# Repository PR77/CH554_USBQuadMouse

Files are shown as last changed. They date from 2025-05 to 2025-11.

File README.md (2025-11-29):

# CH554 USB MOUSE + KEYBOARD <-> AMIGA X-LATER
USB MOUSE + KEYBOARD <-> AMIGA X-LATER based on the WCH554 MCS51 based chip with USB Device + Host Interface. 

# Warning
This design has not been compliance tested and will not be. It may cause personal damage to you or others. I take no responsibility for this. I accept no responsibility for any damage to any equipment that results from the use of this design and its components. IT IS ENTIRELY AT YOUR OWN RISK!

# Overview
This project allows you to use a USB mouse or keyboard on an Amiga computer - of course only one-or-the-other is supported at any one time. It essentially converts a USB mouse to generate a quadrature signal stream, similarly it converts a USB keyboard keycodes (currently only DE is implemented) to work with an Amiga. There are many variants of such a project available, either using this micro controller or others, however I'm using this project as an opportunity to learn more about the WCH55x micro controller.

# Appearance Breadboard Version
I forgot to take a picture of the mess of wires breadboard version, so here is a picture on some perf-board instead. I'm using the USB B socket for debugging and the USB A socket is for the Mouse Connection. Of course only 1 device (either PC for debugging or Mouse for using) can be connected. I got the two USB sockets from an old printer board I found lying around the house.

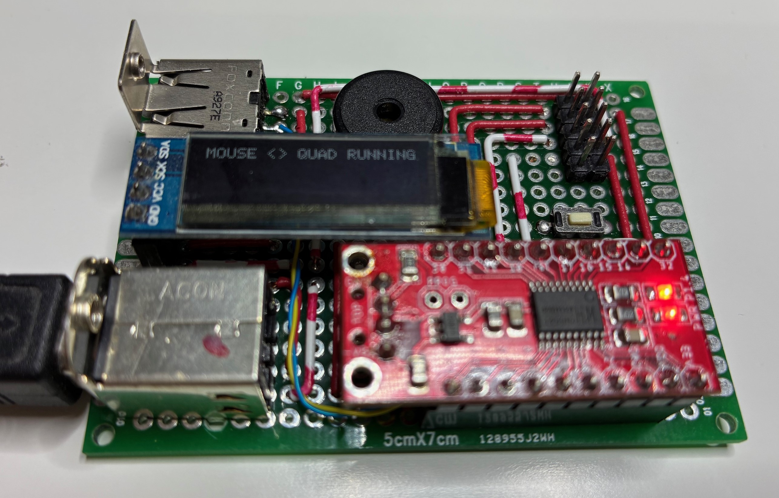
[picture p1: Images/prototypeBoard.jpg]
Perfboard


# Appearance Final PCB Version
PCB version has been routed and manufactured for supporting a mouse or keyboard. Here is the usual 3D artwork of the design.

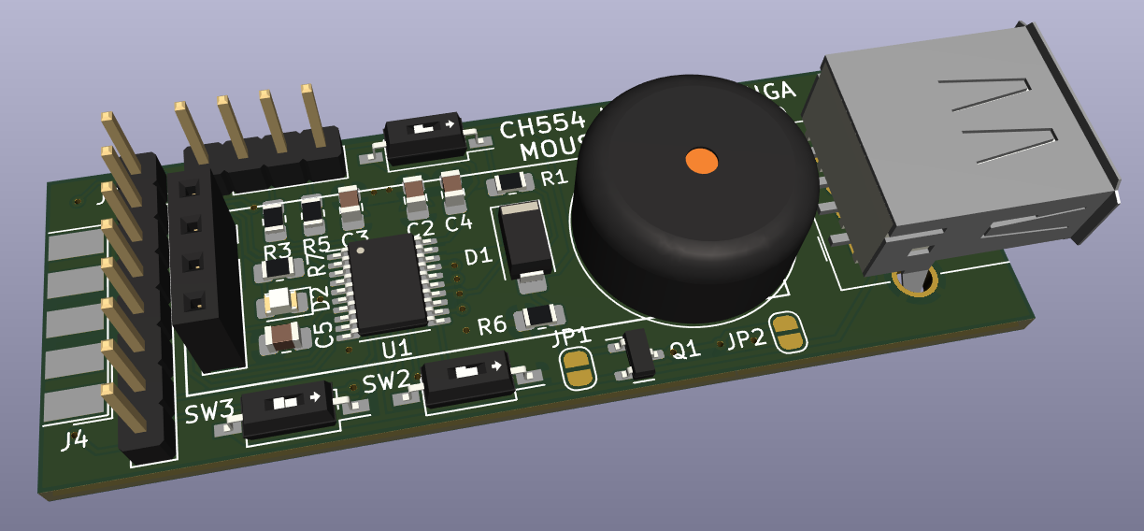
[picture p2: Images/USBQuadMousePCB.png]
PCB


OLED is also supported so you can see some information for example keyboard and mouse report data.

# Credits
I refacted a lot of the original libraries into various software components. However there were some repos which provided me with excellent information, tools and resources;
- https://github.com/wagiminator
- https://github.com/Blinkinlabs/ch554_sdcc
- https://github.com/HonghongLu/CH554

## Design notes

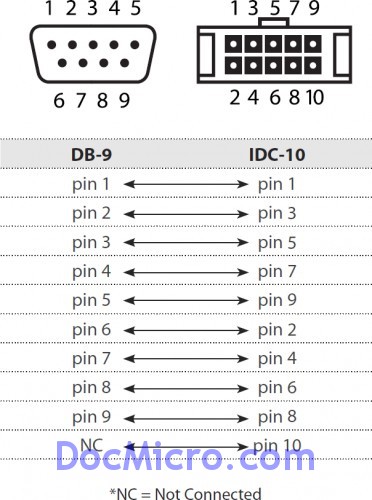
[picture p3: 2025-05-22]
Documents/DB_9 IDC_10.jpg

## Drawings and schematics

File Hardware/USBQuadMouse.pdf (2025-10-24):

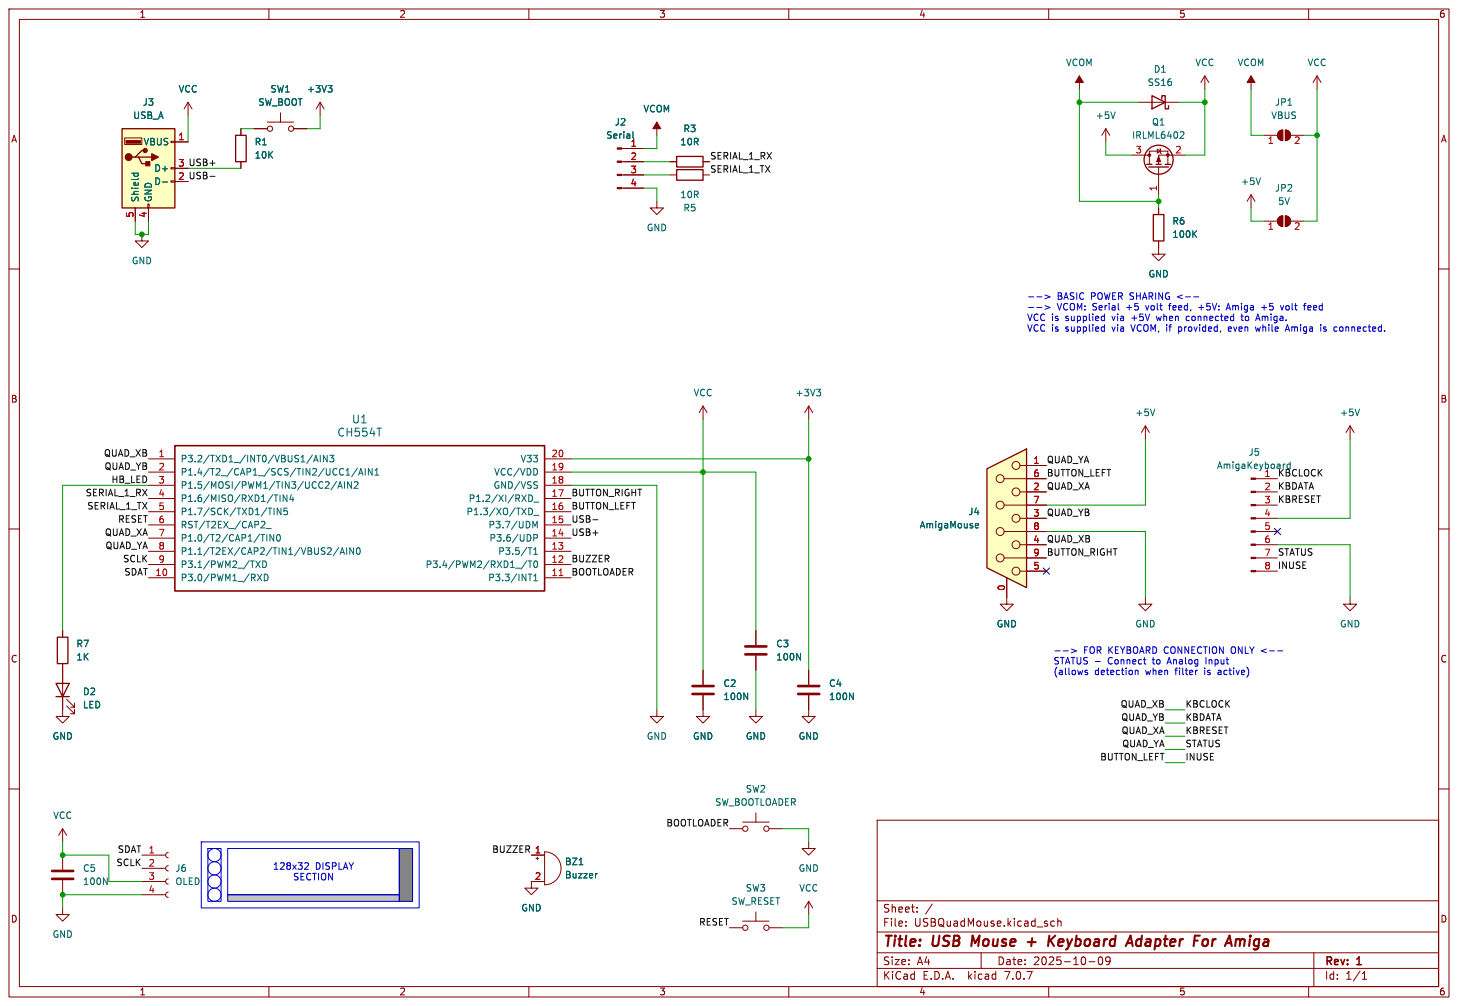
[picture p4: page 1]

File: USBQuadMouse.kicad_sch Sheet: /
Id: 1/1 Title: USB Mouse + Keyboard Adapter For Amiga

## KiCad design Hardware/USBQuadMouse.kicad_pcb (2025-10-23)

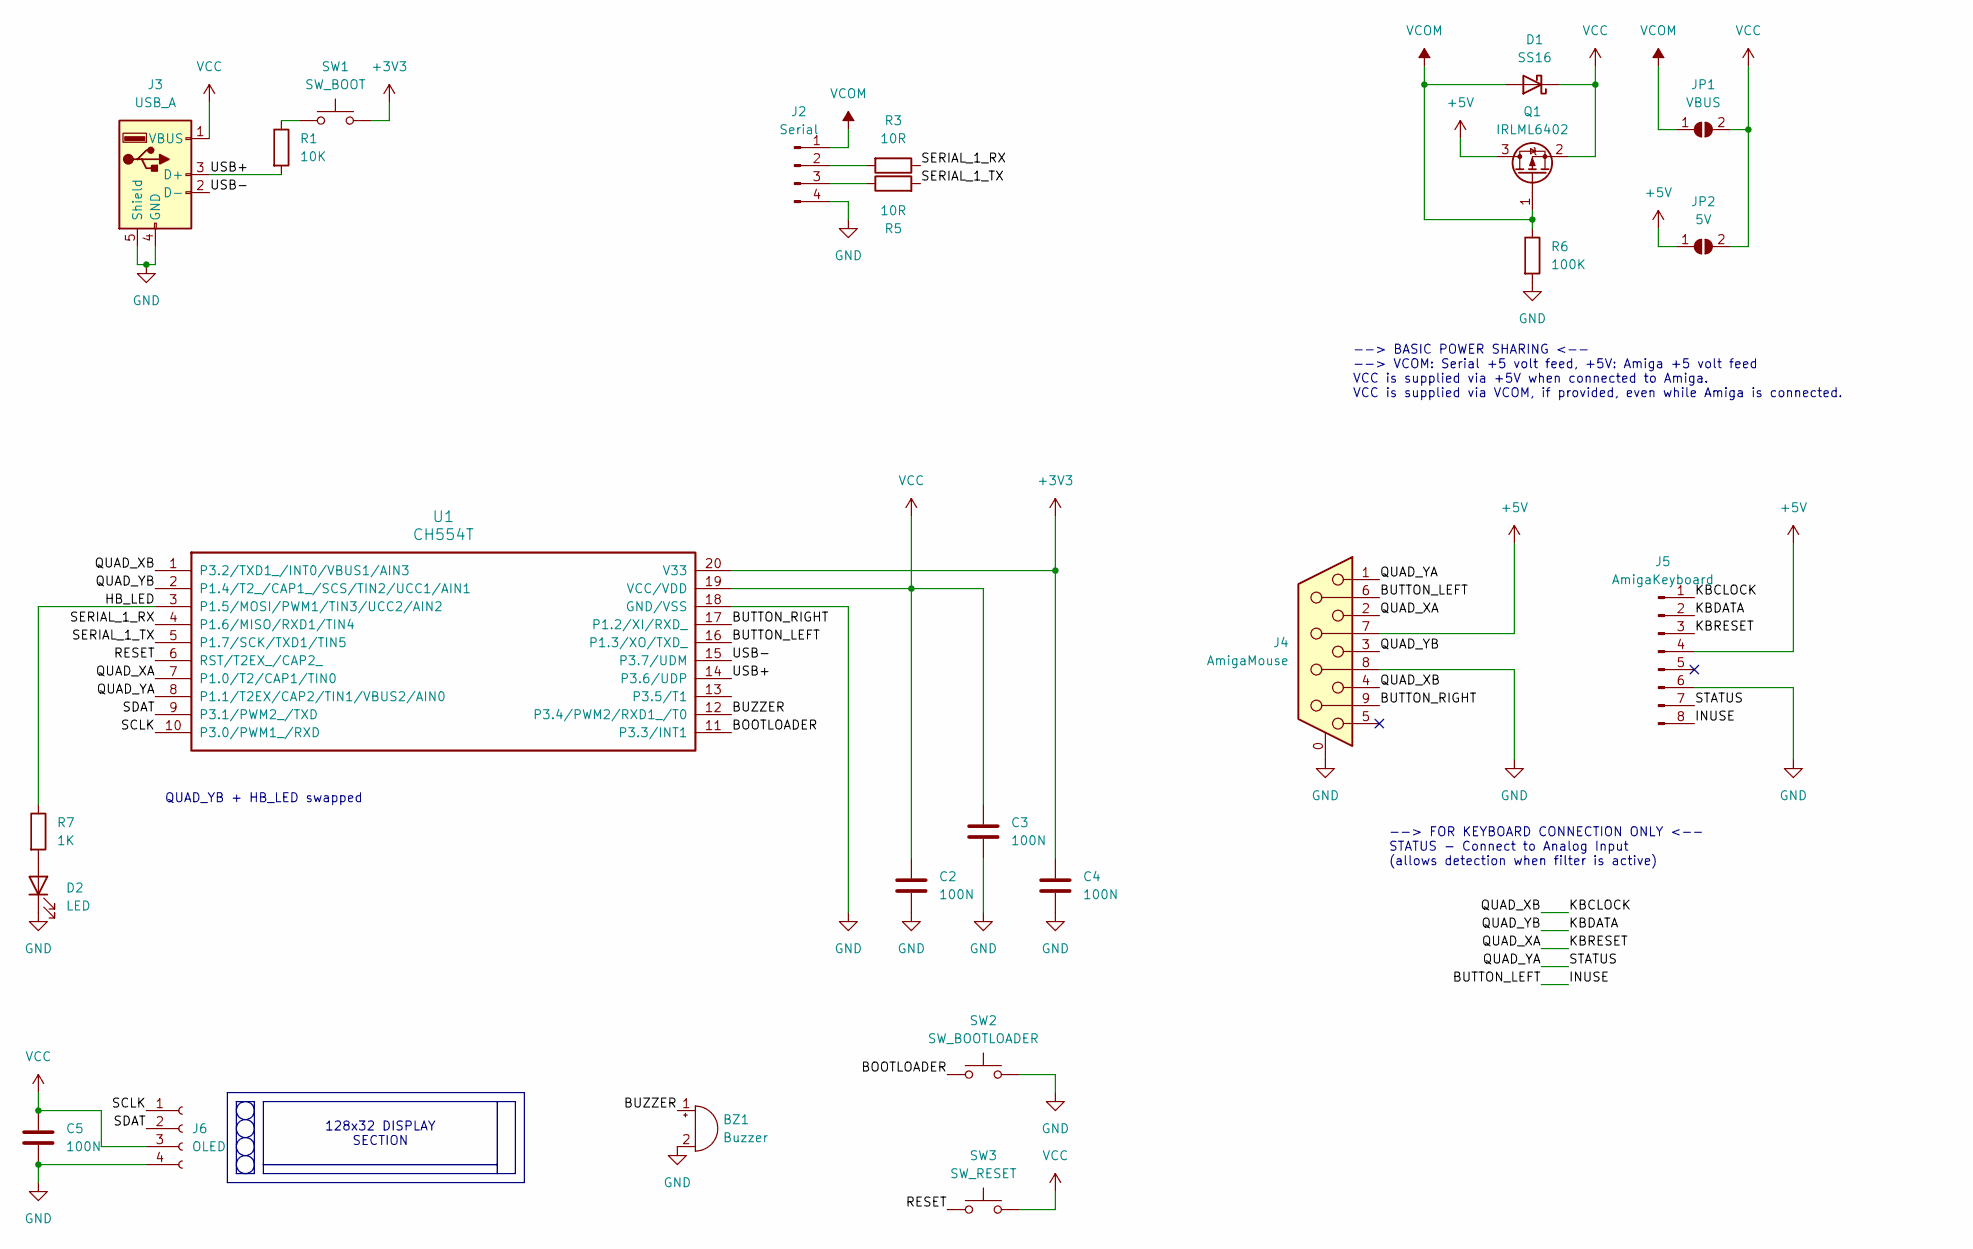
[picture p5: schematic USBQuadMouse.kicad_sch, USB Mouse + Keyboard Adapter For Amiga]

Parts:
BZ1: Buzzer; Buzzer_15x7.5RM7.6
C2, C3, C4, C5: 100N; C_0805_2012Metric_Pad1.18x1.45mm_HandSolder
D1: SS16; D_SMA
D2: LED; LED_0805_2012Metric_Pad1.15x1.40mm_HandSolder
J2: Serial; PinHeader_1x04_P2.54mm_Vertical
J3: USB_A; USB_A_Molex_67643_Horizontal
J4: AmigaMouse; DSUB-9_Female_EdgeMount_P2.77mm
J5: AmigaKeyboard; PinHeader_1x08_P2.54mm_Vertical
J6: OLED; PinSocket_1x04_P2.54mm_Vertical
JP1: VBUS; SolderJumper-2_P1.3mm_Open_RoundedPad1.0x1.5mm
JP2: 5V; SolderJumper-2_P1.3mm_Open_RoundedPad1.0x1.5mm
Q1: IRLML6402; SOT-23
R1: 10K; R_0805_2012Metric_Pad1.20x1.40mm_HandSolder
R3, R5: 10R; R_0805_2012Metric_Pad1.20x1.40mm_HandSolder
R6: 100K; R_0805_2012Metric_Pad1.20x1.40mm_HandSolder
R7: 1K; R_0805_2012Metric_Pad1.20x1.40mm_HandSolder
SW1: SW_BOOT; SW_DIP_SPSTx01_Slide_Copal_CHS-01B_W7.62mm_P1.27mm
SW2: SW_BOOTLOADER; SW_DIP_SPSTx01_Slide_Copal_CHS-01B_W7.62mm_P1.27mm
SW3: SW_RESET; SW_DIP_SPSTx01_Slide_Copal_CHS-01B_W7.62mm_P1.27mm
U1: CH554T; TSSOP-20_4.4x6.5mm_P0.65mm; LCSC C2928938

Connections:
+3V3: C4.1, SW1.2, U1.20 (V33)
+5V: J4.7, J5.4, JP2.1 (A), Q1.3 (D)
/BOOTLOADER: SW2.2, U1.11 (P3.3/INT1)
/BUTTON_LEFT: J4.6, J5.8, U1.16 (P1.3/XO/TXD_)
/BUTTON_RIGHT: J4.9, U1.17 (P1.2/XI/RXD_)
/BUZZER: BZ1.1 (-), U1.12 (P3.4/PWM2/RXD1_/T0)
/HB_LED: R7.1, U1.3 (P1.5/MOSI/PWM1/TIN3/UCC2/AIN2)
/KBCLOCK: J4.4, J5.1, U1.1 (P3.2/TXD1_/INT0/VBUS1/AIN3)
/KBDATA: J4.3, J5.2, U1.2 (P1.4/T2_/CAP1_/SCS/TIN2/UCC1/AIN1)
/KBRESET: J4.2, J5.3, U1.7 (P1.0/T2/CAP1/TIN0)
/QUAD_YA: J4.1, J5.7, U1.8 (P1.1/T2EX/CAP2/TIN1/VBUS2/AIN0)
/RESET: SW3.1, U1.6 (RST/T2EX_/CAP2_)
/SCLK: J6.1, U1.10 (P3.0/PWM1_/RXD)
/SDAT: J6.2, U1.9 (P3.1/PWM2_/TXD)
/SERIAL_1_RX: R3.1, U1.4 (P1.6/MISO/RXD1/TIN4)
/SERIAL_1_TX: R5.2, U1.5 (P1.7/SCK/TXD1/TIN5)
/USB+: J3.3 (D+), R1.2, U1.14 (P3.6/UDP)
/USB-: J3.2 (D-), U1.15 (P3.7/UDM)
GND: BZ1.2 (+), C2.2, C3.2, C4.2, C5.2, D2.1 (K), J2.4, J3.4 (GND), J3.5 (Shield), J4.0 (PAD), J4.8, J5.6, J6.4, R6.2, SW2.1, U1.18 (GND/VSS)
unnamed: D2.2 (A), R7.2
unnamed: J2.2, R3.2
unnamed: J2.3, R5.1
unnamed: R1.1, SW1.1
VCC: C2.1, C3.1, C5.1, D1.1 (K), J3.1 (VBUS), J6.3, JP1.2 (B), JP2.2 (B), Q1.2 (S), SW3.2, U1.19 (VCC/VDD)
VCOM: D1.2 (A), J2.1, JP1.1 (A), Q1.1 (G), R6.1

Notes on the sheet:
128x32 DISPLAY SECTION
--> BASIC POWER SHARING <-- --> VCOM: Serial +5 volt feed, +5V: Amiga +5 volt feed VCC is supplied via +5V when connected to Amiga. VCC is supplied via VCOM, if provided, even while Amiga is connected.
QUAD_YB + HB_LED swapped
--> FOR KEYBOARD CONNECTION ONLY <-- STATUS - Connect to Analog Input (allows detection when filter is active)

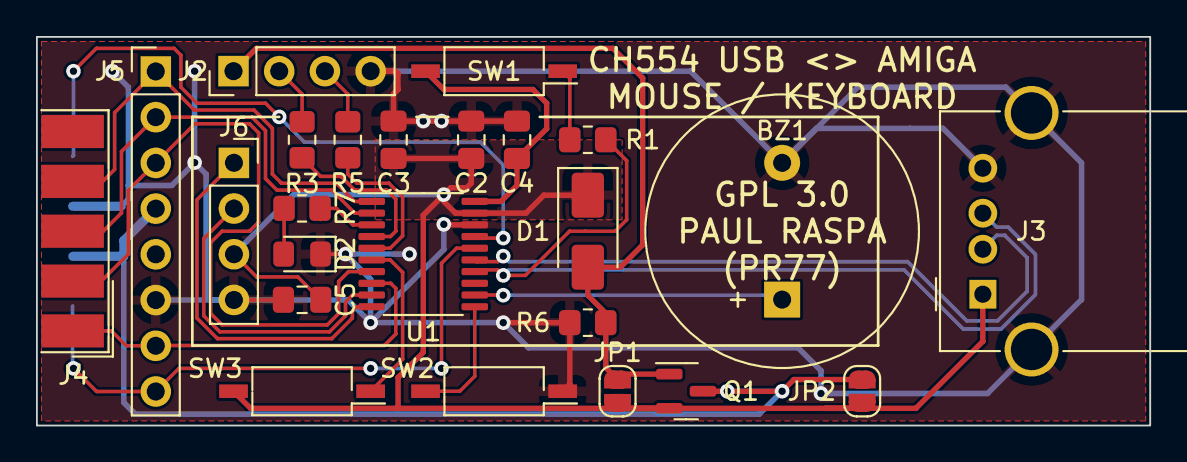
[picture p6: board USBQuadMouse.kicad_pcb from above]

Board: 2 copper layers, 61.8 x 21.6 mm, 24 parts (0 on the bottom side), 25 nets.

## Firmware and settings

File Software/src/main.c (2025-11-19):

/********************************** (C) COPYRIGHT *******************************
* File Name     : MAIN.c
* Author        : Paul Raspa (PR77)
* License       : MIT
* Version       : V1.0
* Date          : 2024/12/17
* Description   : CH554 USB MOUSE + KEYBOARD <-> AMIGA X-LATER
*******************************************************************************/

#include <stdint.h>
#include <compiler.h>
#include "ch554.h"
#include "heartbeat.h"
#include "system.h"
#include "tick.h"
#include "quadrature.h"
#include "keyboard.h"
#include "mouse.h"
#include "buttons.h"
#include "buzzer.h"
#include "i2c.h"
#include "ssd1306.h"
#include "usbhost.h"
#include "serial.h"
#include "bootloader.h"

#define CONSOLE_DEBUG_ENABLED

#define LED_FLASH_RATE_MS           300
#define USB_TRANSFER_RATE_MS        2
#define BUZZER_ACTIVE_DURATION_MS   2

__code uint8_t SetupGetDevDescr[] = { USB_REQ_TYP_IN, USB_GET_DESCRIPTOR, 0x00, USB_DESCR_TYP_DEVICE, 0x00, 0x00, sizeof(USB_DEV_DESCR), 0x00 };
__code uint8_t SetupGetCfgDescr[] = { USB_REQ_TYP_IN, USB_GET_DESCRIPTOR, 0x00, USB_DESCR_TYP_CONFIG, 0x00, 0x00, 0x04, 0x00 };
__code uint8_t SetupSetUsbAddr[] = { USB_REQ_TYP_OUT, USB_SET_ADDRESS, USB_DEVICE_ADDR, 0x00, 0x00, 0x00, 0x00, 0x00 };
__code uint8_t SetupSetUsbConfig[] = { USB_REQ_TYP_OUT, USB_SET_CONFIGURATION, 0x00, 0x00, 0x00, 0x00, 0x00, 0x00 };
__code uint8_t SetupSetUsbInterface[] = { USB_REQ_RECIP_INTERF, USB_SET_INTERFACE, 0x00, 0x00, 0x00, 0x00, 0x00, 0x00 };
__code uint8_t SetupClrEndpStall[] = { USB_REQ_TYP_OUT | USB_REQ_RECIP_ENDP, USB_CLEAR_FEATURE, 0x00, 0x00, 0x00, 0x00, 0x00, 0x00 };
__code uint8_t SetupSetHIDIdle[]= { 0x21, HID_SET_IDLE, 0x00, 0x00, 0x00, 0x00, 0x00, 0x00 };
__code uint8_t SetupGetHIDDevReport[] = { 0x81, USB_GET_DESCRIPTOR, 0x00, USB_DESCR_TYP_REPORT, 0x00, 0x00, 0xFF, 0x00 };
__code uint8_t SetupGetHubDescr[] = { HUB_GET_HUB_DESCRIPTOR, HUB_GET_DESCRIPTOR, 0x00, USB_DESCR_TYP_HUB, 0x00, 0x00, sizeof(USB_HUB_DESCR), 0x00 };

__xdata uint8_t UsbDevEndp0Size;
__xdata __at (0x0000) uint8_t TxBuffer[MAX_PACKET_SIZE];  // OUT, must even address
__xdata __at (0x0040) uint8_t RxBuffer[MAX_PACKET_SIZE];  // IN, must even address

uint8_t Set_Port = 0;
__xdata _RootHubDev ThisUsbDev;                             // ROOT
__xdata _DevOnHubPort DevOnHubPort[HUB_MAX_PORTS];          // Assumption: no more than 1 external HUB, each external HUB does not exceed HUB_MAX_PORTS ports (don’t care if there are more)
__bit FoundNewDev;

#define LOG(msg)   {serial_printString(__FILE__); serial_printCharacter(' '); serial_printHexWord(__LINE__); serial_printCharacter(' '); serial_printString(msg); serial_printString("\n\r");}

void main(void) {
    static __xdata uint32_t previousCountLEDFlash = 0, previousCountUSBTransfer = 0;
    static __xdata uint8_t mouseInitialised = 0, keyboardInitialised = 0;
    uint8_t usbStatus = (uint8_t)ERR_USB_UNKNOWN, len = 0, endp = 0;
    uint16_t usbLocation = 0;

    // Setup low level system and bootloader
    system_disableGlobalInterupts();
    system_CfgFsys();
    bootloader_initialise();

    // Setup timer ticks
    tick_initialiseTimer0();
    tick_enableTimer0Interrupt();

    // Setup heartbeat LED
    heartbeat_initialise();

#if defined(CONSOLE_DEBUG_ENABLED)
    // Setup serial port (debug)
    serial_initialiseSerial1(SERIAL_BAUD_RATE, 0);
#endif // CONSOLE_DEBUG_ENABLED

    // Setup i2c and SSD1306 OLED
    i2c_initialise();
    ssd1306_initialise();
    ssd1306_clearScreen();

    // Setup and initialise USB host
    InitUSB_Host();

    // Setup buzzer with default frequency
    buzzer_initialise(0);

    // Start timer tick and enable global interrupts
    tick_startTimer0();
    system_enableGlobalInterupts();

    // Application code starts here ...
    ssd1306_setCursor(0, 0);
    ssd1306_printString("USB <-> AMIGA X-LATER");
#if defined(CONSOLE_DEBUG_ENABLED)
    serial_printString("\x1b[2J\x1b[HUSB MOUSE + KEYBOARD <-> AMIGA X-LATER RUNNING...\n\r");
#endif // CONSOLE_DEBUG_ENABLED

    while (1) {

#if defined(CONSOLE_DEBUG_ENABLED)
        uint16_t characterToEcho = serial_getCharacter(0);

        if ((characterToEcho != RECEIVE_TIMEOUT) && (characterToEcho != RECEIVE_NO_DATA_AVAIL)) {
            serial_printCharacter((char)characterToEcho);    
        }
#endif // CONSOLE_DEBUG_ENABLED

        if (bootloader_checkBootloaderRequest()) {
            buzzer_stopBuzzer();
            ssd1306_clearScreen();
            ssd1306_setCursor(0, 0);
            ssd1306_printString("---- BOOT LOADER ----");
            bootloader_enter();
        }

        if ((tick_get1msTimerCount() - previousCountLEDFlash) > LED_FLASH_RATE_MS) {
            previousCountLEDFlash += LED_FLASH_RATE_MS;

            heartbeat_toggleState();
        }

        if (UIF_DETECT) {
            UIF_DETECT = 0;
            usbStatus = AnalyzeRootHub();
            if (ERR_USB_CONNECT == usbStatus) {
                FoundNewDev = 1;

                ssd1306_setCursor(0, 1);
                ssd1306_printString("CONNECTED USB DEVICE ");
                ssd1306_setCursor(0, 2);
                ssd1306_printString("                     ");
                ssd1306_setCursor(0, 3);
                ssd1306_printString("                     ");
            }

            if (ERR_USB_DISCON == usbStatus) {
                FoundNewDev = 0;

                ssd1306_setCursor(0, 1);
                ssd1306_printString("REMOVED USB DEVICE   ");
                ssd1306_setCursor(0, 2);
                ssd1306_printString("                     ");
                ssd1306_setCursor(0, 3);
                ssd1306_printString("                     ");
            }
        }

        if (FoundNewDev) {
            FoundNewDev = 0;

            usbStatus = EnumAllRootDevice();
            if (ERR_SUCCESS != usbStatus) {
                ssd1306_setCursor(0, 2);
                ssd1306_printString("ENUMERATION ERROR  ");
                ssd1306_printHexByte(usbStatus);
            } else {
                // Logic to initialise / deinitialise Mouse or Keyboard depending
                // on what device has been inserted or removed.

                if (SearchTypeDevice(DEV_TYPE_KEYBOARD) != 0xFFFF) {
                    // Keyboard found and enumerated.

                    if (mouseInitialised) {
                        mouse_deinitialise();
                        mouseInitialised = 0;
                    }

                    if (!keyboardInitialised) {
                        // Setup Amiga keyboard emulation
                        keyboard_initialise();
                        buzzer_pulseBuzzer(BUZZER_ACTIVE_DURATION_MS);
                        keyboardInitialised = 1;
                    }
                }

                if (SearchTypeDevice(DEV_TYPE_MOUSE) != 0xFFFF) {
                    // Mouse found and enumerated.

                    if (keyboardInitialised) {
                        keyboard_deinitialise();
                        keyboardInitialised = 0;
                    }

                    if (!mouseInitialised) {
                        // Setup quadrature encoder and mouse button emulation
                        mouse_initialise();
                        buzzer_pulseBuzzer(BUZZER_ACTIVE_DURATION_MS);
                        mouseInitialised = 1;
                    }
                }  
            }
        }

        if (keyboardInitialised) {
            keyboard_cyclicHanlder();
        }

        if ((tick_get1msTimerCount() - previousCountUSBTransfer) > USB_TRANSFER_RATE_MS) {
            previousCountUSBTransfer += USB_TRANSFER_RATE_MS;

            // Keyboard emulation --->

            usbLocation = SearchTypeDevice(DEV_TYPE_KEYBOARD);
            if (usbLocation != 0xFFFF) {                                     // found a keyboard
                ssd1306_setCursor(0, 2);
                ssd1306_printString("KEYBOARD @ LOC ");
                ssd1306_printHexWord(usbLocation);
            
                ssd1306_setCursor(0, 3);
                SelectHubPort(usbLocation);                                 // select to operate designated ROOT-HUB port, set current USB speed and USB address of operated device
                usbLocation = usbLocation >> 8;                             // CH554 has only one USB, only the lower eight bits are required

                if (usbLocation) {
                    endp = DevOnHubPort[usbLocation-1].GpVar[0];            // address of interrupt endpoint, bit 7 is used for synchronization flag bit
                } else {
                    endp = ThisUsbDev.GpVar[0];
                }

                if (endp & USB_ENDP_ADDR_MASK) {                             // endpoint valid
                    // CH554 transmit transaction, get data, NAK does not retry
                    usbStatus = USBHostTransact(USB_PID_IN << 4 | endp & 0x7F, endp & 0x80 ? bUH_R_TOG | bUH_T_TOG : 0, 0);
                    if (usbStatus == ERR_SUCCESS) {
                        endp ^= 0x80;                                       // flip sync flag

                        if (usbLocation) {
                            DevOnHubPort[usbLocation-1].GpVar[0] = endp;    // save synchronization flag
                        } else { 
                            ThisUsbDev.GpVar[0] = endp;
                        }
                
                        len = USB_RX_LEN;                                   // received data length
                        if ((len) && (len <= DEFAULT_ENDP0_SIZE)) {
                            const keymapLayout_s * receivedKey = 0;
                            for (uint8_t i = 0; i < sizeof(devTypeKeyboardPayload_s); i++) {
                                ssd1306_printHexByte((uint8_t)(RxBuffer[i]));
                            }

                            ssd1306_printString(", ");

                            if (kbResetAsserted == keyboard_translateReset(RxBuffer[0])) {
                                ssd1306_printString("RST");    
                            } else {
                                if (keyboard_translateKey((devTypeKeyboardPayload_s *)RxBuffer, &receivedKey)) {
                                    ssd1306_printCharacter(receivedKey->asciiCode);
                                } else ssd1306_printString("   ");
                            }
                        }
                    } else if (usbStatus != (USB_PID_NAK | ERR_USB_TRANSFER)) {
                        ssd1306_printString("K-BRD ERROR DETECTED ");
                    }
                } else {
                    ssd1306_printString("NO INTRPT END POINT  ");
                }
            }

            // Mouse emulation --->

            usbLocation = SearchTypeDevice(DEV_TYPE_MOUSE);
            if (usbLocation != 0xFFFF) {                                     // found a mouse (how to deal with two mice?)
                ssd1306_setCursor(0, 2);
                ssd1306_printString("MOUSE @ LOC ");
                ssd1306_printHexWord(usbLocation);
            
                ssd1306_setCursor(0, 3);
                SelectHubPort(usbLocation);                                 // select to operate designated ROOT-HUB port, set current USB speed and USB address of operated device
                usbLocation = usbLocation >> 8;                             // CH554 has only one USB, only the lower eight bits are required

                if (usbLocation) {
                    endp = DevOnHubPort[usbLocation-1].GpVar[0];            // address of interrupt endpoint, bit 7 is used for synchronization flag bit
                } else {
                    endp = ThisUsbDev.GpVar[0];
                }

                if (endp & USB_ENDP_ADDR_MASK) {                             // endpoint valid
                    // CH554 transmit transaction, get data, NAK does not retry
                    usbStatus = USBHostTransact(USB_PID_IN << 4 | endp & 0x7F, endp & 0x80 ? bUH_R_TOG | bUH_T_TOG : 0, 0);
                    if (usbStatus == ERR_SUCCESS) {
                        endp ^= 0x80;                                       // flip sync flag

                        if (usbLocation) {
                            DevOnHubPort[usbLocation-1].GpVar[0] = endp;    // save synchronization flag
                        } else { 
                            ThisUsbDev.GpVar[0] = endp;
                        }
                
                        len = USB_RX_LEN;                                   // received data length
                        if ((len) && (len <= DEFAULT_ENDP0_SIZE)) {
                            for (uint8_t i = 0; i < sizeof(devTypeMousePayload_s); i++) {
                                ssd1306_printHexByte((uint8_t)(RxBuffer[i]));
                            }
                            ssd1306_printString(", ");

                            if (mouse_translateMovement((devTypeMousePayload_s *)RxBuffer)) {
                                ssd1306_printHexByte(quadrature_getCounts(QUADRATURE_X_CHANNEL));
                                ssd1306_printString(", ");
                                ssd1306_printHexByte(quadrature_getCounts(QUADRATURE_Y_CHANNEL));
                                ssd1306_printString(", ");
                            } else ssd1306_printString("00, 00, ");

                            ssd1306_printString(mouse_getButtonString((devTypeMousePayload_s *)RxBuffer));
                        }
                    } else if (usbStatus != (USB_PID_NAK | ERR_USB_TRANSFER)) {
                        ssd1306_printString("MOUSE ERROR DETECTED ");
                    }
                } else {
                    ssd1306_printString("NO INTRPT END POINT  ");
                }
            }
        }
    }
} 

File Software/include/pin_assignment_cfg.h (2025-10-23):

/********************************** (C) COPYRIGHT *******************************
* File Name     : PIN_ASSIGNMENT_CFG.H
* Author        : Paul Raspa (PR77)
* License       : MIT
* Version       : V1.0
* Date          : 2025/05/19
* Description   : Pin Assignments
*******************************************************************************/

#ifndef __CH554_PIN_ASSIGNMENT_CFG_H__
#define __CH554_PIN_ASSIGNMENT_CFG_H__

#include <stdint.h>
#include "ch554.h"

// Port 1

#ifndef QUADRATURE_XA_ASSIGNED_PIN
#define QUADRATURE_XA_ASSIGNED_PIN          1.0
#endif

#ifndef QUADRATURE_YA_ASSIGNED_PIN
#define QUADRATURE_YA_ASSIGNED_PIN          1.1
#endif

#ifndef RIGHT_BUTTON_ASSIGNED_PIN
#define RIGHT_BUTTON_ASSIGNED_PIN           1.2
#endif

#ifndef LEFT_BUTTON_ASSIGNED_PIN
#define LEFT_BUTTON_ASSIGNED_PIN            1.3
#endif

#ifndef HEARTBEAT_ASSIGNED_PIN
#if defined(PCB_LAYOUT)
    #define HEARTBEAT_ASSIGNED_PIN          1.5
    #else
    #define HEARTBEAT_ASSIGNED_PIN          1.4
#endif
#endif

#ifndef QUADRATURE_YB_ASSIGNED_PIN
#if defined(PCB_LAYOUT)
    #define QUADRATURE_YB_ASSIGNED_PIN      1.4 
    #else
    #define QUADRATURE_YB_ASSIGNED_PIN      1.5 
#endif
#endif

// Port 3

#ifndef I2C_SDAT_PIN
#if defined(PCB_LAYOUT)
    #define I2C_SDAT_ASSIGNED_PIN           3.0
    #else
    #define I2C_SDAT_ASSIGNED_PIN           3.1
#endif
#endif

#ifndef I2C_SCLK_PIN
#if defined(PCB_LAYOUT)
    #define I2C_SCLK_ASSIGNED_PIN           3.1
    #else
    #define I2C_SCLK_ASSIGNED_PIN           3.0
#endif
#endif

#ifndef QUADRATURE_XB_ASSIGNED_PIN
#define QUADRATURE_XB_ASSIGNED_PIN          3.2
#endif

#ifndef BOOTLOADER_ASSIGNED_PIN
#define BOOTLOADER_ASSIGNED_PIN             3.3
#endif

#ifndef BUZZER_OUTPUT_ASSIGNED_PIN
#define BUZZER_OUTPUT_ASSIGNED_PIN          3.4
#endif

#endif // __CH554_PIN_ASSIGNMENT_CFG_H__

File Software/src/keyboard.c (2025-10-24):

/********************************** (C) COPYRIGHT *******************************
* File Name     : KEYBOARD.C
* Author        : Paul Raspa (PR77)
* License       : MIT
* Version       : V1.0
* Date          : 2025/10/23
* Description   : CH554 Amiga Keyboard Emulation
*******************************************************************************/

#include <stdint.h>
#include "ch554.h"
#include "keyboard.h"
#include "keyboard_cfg.h"
#include "keyboard_layout.h"
#include "system.h"

SBIT(KBCLOCK, KBCLOCK_PORT, KBCLOCK_PIN);
SBIT(KBDATA, KBDATA_PORT, KBDATA_PIN);
SBIT(KBRESET, KBRESET_PORT, KBRESET_PIN);
SBIT(KBSTATUS, KBSTATUS_PORT, KBSTATUS_PIN);
SBIT(KBINUSE, KBINUSE_PORT, KBINUSE_PIN);

static const uint8_t keycode2ascii[128][3] =  {DE_KEYCODE_TO_ASCII};
// THIS IS ASCII - NEEDS TO BE UPDATED TO AMIGA KEYCODES

void keyboard_initialise(void) {

    KBCLOCK_MOD_OC = KBCLOCK_MOD_OC & ~(1 << KBCLOCK_PIN);
    KBCLOCK_DIR_PU = KBCLOCK_DIR_PU | (1 << KBCLOCK_PIN);

    KBDATA_MOD_OC = KBDATA_MOD_OC & ~(1 << KBDATA_PIN);
    KBDATA_DIR_PU = KBDATA_DIR_PU | (1 << KBDATA_PIN);

    KBRESET_MOD_OC = KBRESET_MOD_OC & ~(1 << KBRESET_PIN);
    KBRESET_DIR_PU = KBRESET_DIR_PU | (1 << KBRESET_PIN);
    KBRESET = 1;

    KBSTATUS_MOD_OC = KBSTATUS_MOD_OC | (1 << KBSTATUS_PIN);
    KBSTATUS_DIR_PU = KBSTATUS_DIR_PU | (1 << KBSTATUS_PIN);

    KBINUSE_MOD_OC = KBINUSE_MOD_OC | (1 << KBINUSE_PIN);
    KBINUSE_DIR_PU = KBINUSE_DIR_PU | (1 << KBINUSE_PIN);
}

void keyboard_sendKey(uint8_t keyCode, uint8_t pressedReleased) {
    //         _____   ___   ___   ___   ___   ___   ___   ___   _________
    // KBCLOCK      \_/   \_/   \_/   \_/   \_/   \_/   \_/   \_/
    //         ___________________________________________________________
    // KBDATA     \_____X_____X_____X_____X_____X_____X_____X_____/
    //           (6)   (5)   (4)   (3)   (2)   (1)   (0)   (7)
    //
    //          First                                     Last
    //          sent                                      sent

    // Code taken from repo here: https://github.com/PR77/PS2_Keyboard_Adapter

    uint8_t z = 0x80; 
    uint8_t keyCodeToSend = (keyCode << 1);

    keyCodeToSend |= (pressedReleased) ? 0x00 : 0x01; 

    KBDATA = 1;
    KBCLOCK = 1;

    for (uint8_t i = 0; i < 8; i++) {
        KBDATA = !(keyCodeToSend & z);
        
        system_mDelayuS(20);
        KBCLOCK = 0;
        system_mDelayuS(20);
        KBCLOCK = 1;

        z = z >> 1 ;
    }

    system_mDelayuS(200);
}

void keyboard_assertReset(void) {

    KBRESET = 0;
    system_mDelayuS(200);
    KBRESET = 1;
}

keyboardStatus_e keyboard_getStatus(void) {

    return (kbStatusOff);
}

keyboardInUse_e keyboard_getInUse(void) {

    return (kbInUseOff);
}

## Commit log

2025-03-16 Updates
    Quadrature encoder still in development. Will link the execution of the sequencer to Timer 2 interrupt.
2025-03-27 Updates
    Added support for Serial Port 1 transmit interrupts. More to come.
2025-03-28 Updates
    Receive interrupt added, still be debugged.
2025-03-31 Updates
    Fixed #ifdefs to enable or disable TX and RX interrupts.
    [serial_1.c]
2025-04-09 Updates + WIP
    Updates to Serial Driver and WIP on Quadrature Encoder interrupt handler.
2025-05-17 Updates
    Changed pin allocations for prototype board layout.
2025-05-20 Updates
    Updates for prototype board and added buzzer support.
    [main.c, pin_assignment_cfg.h]
2025-05-21 Updates
    Fixed buzzer routines.
    [main.c]
2025-05-21 Updates
    Thanks to "wagiminator" references for setting PWM frequency macro.
2025-05-22 Updates
    Added some usability fixes.
    [main.c, pin_assignment_cfg.h, quadrature.h]
2025-10-09 Updates
    Prep work for PCB version.
2025-10-23 Updates
    Added PCB and framework for Amiga Keyboard emulation.
    [USBQuadMouse.kicad_pcb, USBQuadMouse.kicad_sch]
2025-11-03 Updates
    Fixed some F_CPU / FREQ_SYS macro related issues and improved Serial 1 TX interrupt handler.
2025-11-05 Updates
    Added support to switch automatically between Keyboard or Mouse based on what is connected.
2025-11-20 Updates
    Fixed a nasty bug what would not handle the USB keyboard changing the order of the report content.
    [main.c]
2025-11-21 Updates
    A couple of bug fixes.
2025-11-29 Updates
    Some code quality updates and fixed an annoying bug where the Y Axis would sometime changes direction.

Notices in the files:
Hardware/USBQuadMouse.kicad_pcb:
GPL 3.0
